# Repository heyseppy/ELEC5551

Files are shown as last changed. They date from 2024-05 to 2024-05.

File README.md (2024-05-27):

<p align="center">
  Satellite Image
  <h1>ELEC5551 Electrical Design Project</h1>
  <p1>27/05/2024</p1>
</p>

## Overview
This repository houses all components of the ELEC5551 Electrical Design project conducted at University of Western Australia. The project includes comprehensive designs and software implementations for a sophisticated electrical system, focusing on both onboard and base station functionalities.

## Repository Overview

### Onboard Hardware
| File Path | Description |
|---|---|
| `Cubesat_PCB/PCB_Project/Project Outputs for Telemetery System ` | Gerber files containing whole project |
| `Cubesat_PCB/PCB_Project/Components` | Team 01's custom footprints.|
| `Cubesat_PCB/PCB_Project/History` | Altium version history cache. |

### Base Station Software
| File Path | Description |
|---|---|
| `Base Station Software/CSV/CSVAppend.py` | Logs GPS data into a CSV, ensuring all entries are unique. |
| `Base Station Software/CSV/NewFlight_csv.py` | Prepares for new data collection by replacing the old CSV with a new template, storing past files.|
| `Base Station Software/GPS_Map/GPSPlot.py` | Plots GPS coordinates on a map and visualizes flight paths with altitude indicated by color. |
| `Base Station Software/GPS_Map/Map_Refresh.py` | Prepares for new GPS plot image, provides template PNG of the map and stores old map. |
| `Base Station Software/MainDataProcessing.py` | Processes data received via serial interface to prepare for display and logging for UI. |
| `Base Station Software/ReadDataFromSerialPort.py` | Initiates data reception from the serial interface. |
| `Base Station Software/Start.py` | Initiates CSV appending process for data logging and process for GPS plotting. |
| `Base Station Software/Stop.py` | Terminates data logging and GPS plotting processes; starts scripts for new templates. |
| `Base Station Software/UI/index.html` | HTML file that structures the user interface layout. |
| `Base Station Software/UI/script.js` | JavaScript file that adds interactivity to the user interface. |
| `Base Station Software/UI/styles.css` | CSS file that styles the user interface elements. |

### Base Station Hardware
| File Path | Description |
|---|---|
| `Base Station Hardware / Base_Station_Combined v34` | Contains entire Autodesk Fusion 360 workspace, including simulation models used for thermal and load analysis. 

### Onboard Software
| File Path | Description |
|---|---|
| `Onboard Software / launch / cubesat_program.py ` | All embedded systems code in micropython for running the project. 
| `Onboard Software / launch / cubesat_launch.py ` | A sample launch file for running all the scripts. 
| `Onboard Software / output / output.json ` | Empty file provided for the output to be generated in. 

### FSM Generator
| File Path | Description |
|---|---|
| `FSM Generator / fsm_generator.html ` | Generates the finite state machine for operation of the on-board telemetry system. 
| `FSM Generator / visualiser.html ` | Constructs a visualiser for the functioning finite state machine. 

## PCB Design
The `PCB` directory contains all necessary files for the Printed Circuit Board (PCB) design. Schematic files, Gerber files, and comprehensive documentation about layout and components are designed using Altium. This design ensures efficiency and reliability, maintaining stable performance under diverse operational conditions.

## Onboard Software
The `OnboardSoftware` folder includes all source code for the microcontrollers on the PCB, written in MicroPython. This software manages sensor inputs, communication protocols, and ensures real-time data processing and decision-making, crucial for the system's autonomous functions.

## Base Station Software
In the `BaseStationSoftware` directory, you'll find the software required to interface with the project's base station. This software is crafted using HTML, CSS, and JavaScript, focusing on data acquisition, user interface, and system monitoring. This stack ensures a robust, user-friendly interface for real-time monitoring and control.

## Base Station Hardware
The `BaseStationHardware` folder encompasses detailed designs and specifications for the hardware setup at the base station, crafted in Autodesk Fusion360. This section provides detailed schematics, a list of components, and assembly instructions, facilitating the building and maintenance of the hardware that supports communication with the onboard systems.

## License
The CERN Open Hardware Licence Version 2 - Permissive (CERN-OHL-P) was chosen for its commitment to transparency and collaboration, allowing unrestricted use, modification, and distribution of the hardware designs and documentation. This license facilitates innovation and sharing within the community, ensuring that all adaptations and improvements remain openly accessible under the same terms.

## Acknowledgements
- Special thanks to the ELEC5551 course staff and fellow students for their invaluable feedback and support.

## Contributors
- Jonathon Sader
- William Hor
- Sep Kimiaei
- Carl Alvares
- Liam Kubach
- Aidan Crummey

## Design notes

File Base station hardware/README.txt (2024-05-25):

.f3z document requires Autodesk fusion 360 to open and view the base station CAD project.

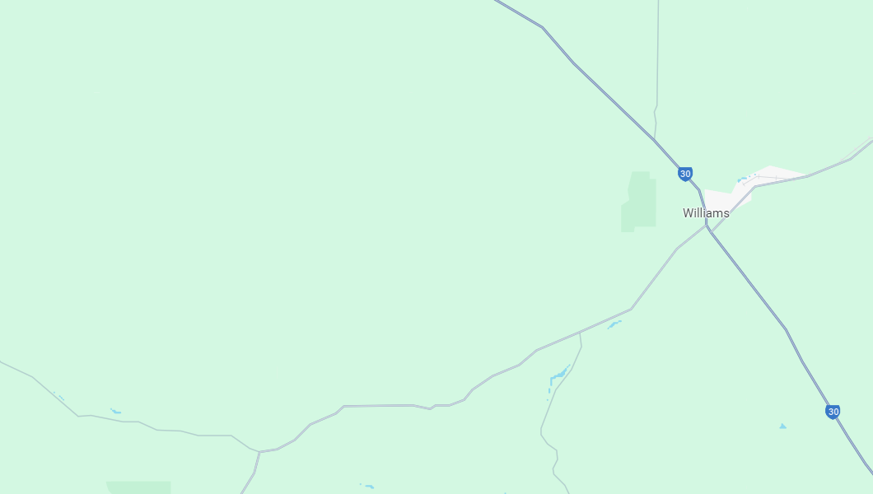
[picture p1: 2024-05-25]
Base station software/GPS_Map/Map Template/template_map.png

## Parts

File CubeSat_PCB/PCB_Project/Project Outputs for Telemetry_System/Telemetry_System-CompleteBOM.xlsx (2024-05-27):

Line # | Name | Description | Designator | Revision ID | Revision State | Revision Status | Quantity | Manufacturer 1 | Manufacturer Part Number 1 | Manufacturer Lifecycle 1 | Supplier 1 | Supplier Part Number 1 | Supplier Unit Price 1 | Supplier Subtotal 1
 | 1 µF | CAP CER 1UF 4V X5R 0402 | C6, C9, C12, C24, C30 |  | Not managed |  | 5 | KYOCERA AVX | 04024D105KAT2A |  | DigiKey | 478-KGM05AR50G105KHCT-ND | 0.02963 | 0.14815
 | 0.1 µF | CAP CER 100NF 10V X7R 0402 | C5, C7, C10, C11, C14, C22, C25, C26, C27, C28 |  | Not managed |  | 12 | Samsung | CL05B104KP5VPNC | Volume Production | Digikey | 1276-CL05B104KP5VPNCCT-ND | 0.0664 | 0.66395
 | 91 kOhms | RES SMD 91K OHM 5% 1/16W 0402 | R10 |  | Not managed |  | 1 | Vishay Dale | CRCW040291K0JNED | Volume Production | Digikey | 541-91KJCT-ND | 0.1509 | 0.1509
 | 511 kOhms | RES SMD 511K OHM 1% 1/16W 0402 | R9 |  | Not managed |  | 1 |  | CRCW0402511KFKED |  | DigiKey | 541-511KLCT-ND | 0.16 | 0.16
 | 10 µF | CAP CER 10UF 4V X5R 0402 | C16, C32, C33 |  | Not managed |  | 4 | Murata | GRM155R60G106ME01D | Volume Production | Digikey | 490-GRM155R60G106ME01DCT-ND | 0.16599 | 0.49796
 | 10000 pF | CAP CER 0402 10NF 16V X7R 10% | C15 |  | Not managed |  | 1 | KEMET | C0402C103K4REC7867 | Volume Production | Digikey | 399-C0402C103K4REC7867CT-ND | 0.16599 | 0.16599
 | 2.2 µF | CAP CER 2.2UF 35V X5R 0402 | C23 |  | Not managed |  | 1 | Murata | GRM155R6YA225KE11D | Volume Production | Digikey | 490-18212-1-ND | 0.24144 | 0.24144
 | 4.7 µF | CAP CER 4.7UF 6.3V X6S 0603 | C4, C20 |  | Not managed |  | 2 | Murata | GRM185C80J475ME11D | Volume Production | Digikey | 490-18660-1-ND | 0.24144 | 0.48287
 | 16 pF | CAP CER 16PF 25V C0G/NP0 0603 | C3, C8 |  | Not managed |  | 2 | KEMET | C0603C160K3GAC7867 | Volume Production | Digikey | 399-C0603C160K3GAC7867CT-ND | 0.28671 | 0.57341
 | 5 pF | CAP CER 5PF 50V 0603 EPOXY | C1, C2 |  | Not managed |  | 2 | TDK | CGA3E2C0G1H050C080AD | Volume Production | Digikey | 445-9797-1-ND | 0.3018 | 0.60359
 | 1 µH | FIXED IND 1UH 1.4A 107 MOHM SMD | L1 |  | Not managed |  | 1 | Murata | LQM2MPN1R0NG0L | Volume Production | Digikey | 490-7784-1-ND | 0.31689 | 0.31689
 | 30 Ohms @ 100 MHz | FERRITE BEAD 30 OHM 0402 1LN | FB1 |  | Not managed |  | 1 | Murata | BLM15PE300SH1D | Volume Production | Digikey | 490-BLM15PE300SH1DCT-ND | 0.31689 | 0.31689
 | 10k | RES 10K OHM 0.1% 1/10W 0402 | R1, R2, R3, R4, R5, R6, R7, R11, R12 |  | Not managed |  | 9 | TE Connectivity | RP73PF1E10KBTD | Volume Production | Digikey | A127415CT-ND | 0.34857 | 3.49
 | 4.7k | RES SMD 4.7K OHM 1% 1/20W 0201 | R13, R14 |  | Not managed |  | 2 | Vishay Dale | CRCW02014K70FKED |  | DigiKey | 541-4.70KAABCT-ND | 0.35 | 0.7
 | 1909763-1 | CONN UMCC JACK STR 50OHM SMD | J1 |  | Not managed |  | 1 | TE Connectivity AMP Connectors | 1909763-1 |  | DigiKey | A118077CT-ND | 0.39526 | 0.39526
 | 47 pF | CAP CER 47PF 16V NP0 0402 | C17, C29 |  | Not managed |  | 2 | KEMET | C0402C470J4GAC7867 | Volume Production | Digikey | 399-14453-1-ND | 0.48287 | 0.96575
 | 47 µF | CAP CER 47UF 4V X5R 0805 | C21 |  | Not managed |  | 1 | Taiyo Yuden | AMK212BBJ476MD-T | Not Recommended for New Design | Digikey | 587-5399-1-ND | 0.55832 | 0.55832
 | 4.7µH | FIXED IND 4.7UH 160MA 2.7 OHM | L2 |  | Not managed |  | 1 | Abracon LLC | AISC-0603F-4R7J-T |  | DigiKey | 535-12533-1-ND | 0.66 | 0.66
 | 22 µF | CAP CER 22UF 10V X5R 0402 | C19 |  | Not managed |  | 1 | Murata | GRM158R61A226ME15D | Volume Production | Digikey | 490-GRM158R61A226ME15DCT-ND | 0.67904 | 0.67904
 | 32.768 kHz | CRYSTAL 32.7680KHZ 12.5PF SMD | Y1 |  | Not managed |  | 1 | Micro Crystal | 201701-MC01 | Unknown | Digikey | 2195-CM8V-T1A-32.768KHZ-12.5PF-20PPM-TB-QACT-ND | 0.7394 | 0.7394
 | 25 MHz | CRYSTAL 25.0000MHZ 18PF SMD | Y2 |  | Not managed |  | 1 | Abracon | ABLS-25.000MHZ-K4F-T | Unknown | Digikey | 535-9956-1-ND | 0.81485 | 0.81485
 | B520C-13-F | DIODE SCHOTTKY 20V 5A SMC | D1 |  | Not managed |  | 1 | Diodes | B520C-13-F | Volume Production | Digikey | B520C-FDICT-ND | 0.84503 | 0.84503
 | S2B-PH-SM4-TB(LF)(SN) | CONN HEADER SMD R/A 2POS 2MM | J6 |  | Not managed |  | 1 |  | S2B-PH-SM4-TB |  | DigiKey | 455-1749-1-ND | 0.93 | 0.93
 | 10 Ohms | TOTAL LEAD-FREE CHIP RESISTOR SU | R8 |  | Not managed |  | 1 | Yageo | SR0402JR-7W10RP | Unknown | Digikey | 13-SR0402JR-7W10RPCT-ND | 0.96575 | 0.96575
 | NPPN061BFLD-RC | CONN HDR 6POS 0.079 GOLD SMD | J8 |  | Not managed |  | 1 | Sullins | NPPN061BFLD-RC | Volume Production | Digikey | S5902-06-ND | 1.09 | 1.09
 | NPPN101BFCN-RC | CONN HDR 10POS 0.079 GOLD PCB | J9, J10 |  | Not managed |  | 2 | Sullins | NPPN101BFCN-RC | Volume Production | Digikey | S5751-10-ND | 1.49 | 2.99
 | J_581-M09-213L462 | 9P D-Sub Panel Mounting 2 Gold - D-Sub / VGA connector ROHS | J7 |  | Not managed |  | 1 | NorComp | 581-M09-213L462 | Volume Production | LCSC | C17556964 | 50.8857 | 50.8857
 | J_B4B-PH-SM4-TB | 1x4P 4P PH Tin 4 -25â„ƒ~+85â„ƒ 2A 1 2mm Copper Alloy Brick nogging SMD,P=2mm Wire To Board Connector ROHS | J2, J3, J5 |  | Not managed |  | 3 | JST | B4B-PH-SM4-TB | Volume Production | LCSC | C160354 | 0.1921 | 0.5763
 | J_DM3CS-SF | 1.83mm Gold Deck MicroSD card (TF card) Pluggable SMD SD Card / Memory Card Connector ROHS | J4 |  | Not managed |  | 1 | HRS(Hirose) | DM3CS-SF | Volume Production | LCSC | C202111 | 1.377 | 1.377
 | NEO-M9N-00B | SMD-24P Satellite Positioning Modules ROHS | U4 |  | Not managed |  | 1 | U-BLOX | NEO-M9N-00B | Volume Production | LCSC | C5119087 | 41.1692 | 41.1692
 | TPS631000DRLR | 2A 1.2V~5.3V 1.6V~5.5V SOT-583 DC-DC Converters ROHS | U5 |  | Not managed |  | 1 | Texas Instruments | TPS631000DRLR | Volume Production | LCSC | C5219190 | 1.6408 | 1.6408
 | U_430182043816 | Round Button 50mA Brick nogging SPST - NO 160gf 12V SMD Tactile Switches ROHS | U2 |  | Not managed |  | 1 | Wurth Elektronik | 430182043816 | Volume Production | LCSC | C5311656 | 0.6183 | 0.6183
 | U_BME280 | LGA-8(2.5x2.5) Temperature and Humidity Sensor ROHS | U9 |  | Not managed |  | 1 | Bosch Sensortec | BME280 | Volume Production | LCSC | C92489 | 3.4287 | 3.4287
 | U_BQ27427YZFR | Polymer 1 DSBGA-9 Battery Management ICs ROHS | U6 |  | Not managed |  | 1 | Texas Instruments | BQ27427YZFR | Volume Production | LCSC | C6075475 | 1.2015 | 1.2015
 | U_LSM9DS1TR | LGA-24(3x3.5) Attitude Sensor/Gyroscope ROHS | U3 |  | Not managed |  | 1 | STMicroelectronics | LSM9DS1TR | Volume Production | LCSC | C2655096 | 7.2046 | 7.2046
 | U_STM32F411CEU6 | 512KB 1.7V~3.6V ARM-M4 128KB 100MHz FLASH 36 UFQFPN-48(7x7) Microcontroller Units (MCUs/MPUs/SOCs) ROHS | U1 |  | Not managed |  | 1 | STMicroelectronics | STM32F411CEU6 | Volume Production | LCSC | C60420 | 2.369 | 2.369
 | U_TCA9406DCUR | 2.3V~5.5V 1 2 1.65V~3.6V 24Mbps VSSOP-8-0.5mm Translators / Level Shifters ROHS | U8 |  | Not managed |  | 1 | Texas Instruments | TCA9406DCUR | Volume Production | LCSC | C840107 | 0.4531 | 0.4531
 | U_TPS62745DSSR | Step-down type WSON-12-EP(2x3) DC-DC Converters ROHS | U7 |  | Not managed |  | 1 | Texas Instruments | TPS62745DSSR | Volume Production | LCSC | C91940 | 0.686 | 0.686
 |  |  |  |  |  |  |  |  |  |  |  |  | Total | 131.75564

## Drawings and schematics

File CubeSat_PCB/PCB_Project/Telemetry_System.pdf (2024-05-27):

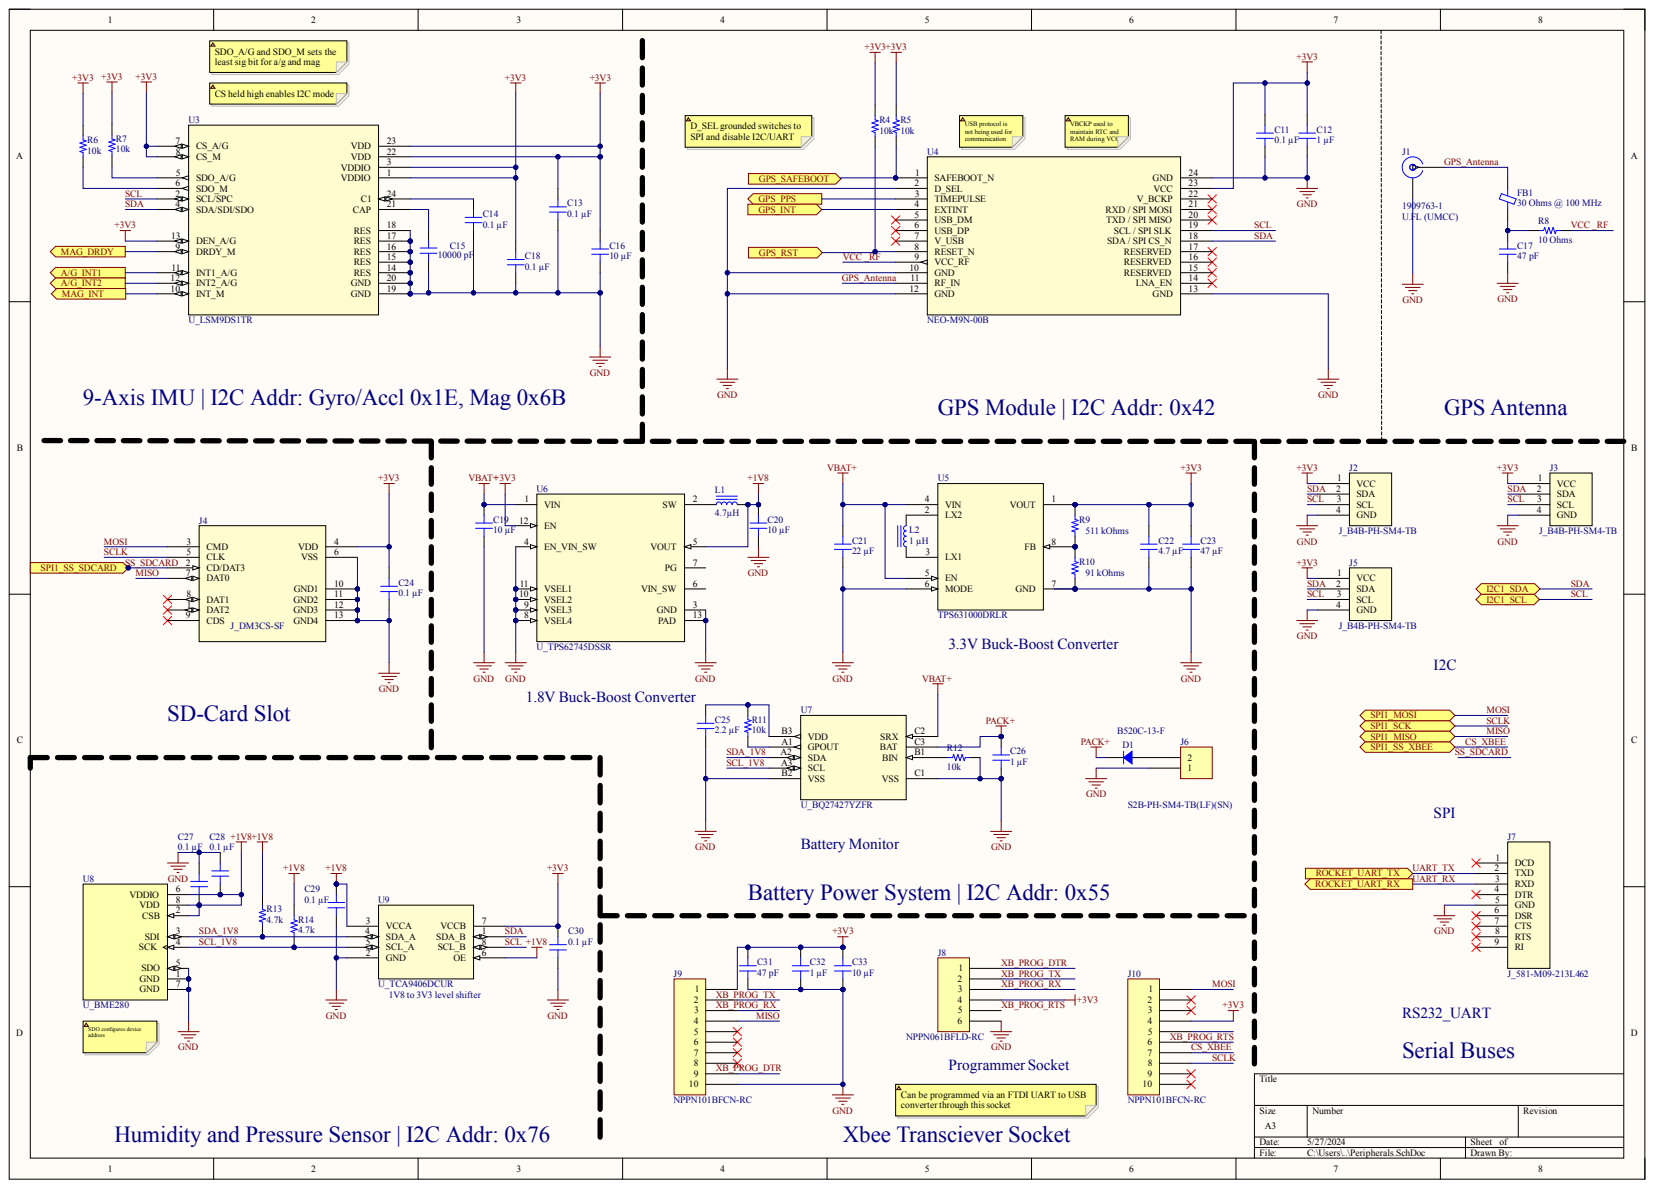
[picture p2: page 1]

SDO_A/G and SDO_M sets the
least sig bit for a/g and mag

CS held high enables I2C mode

D_SELgrounded switches to
SPI and disable I2C/UART

USB protocol is
not being used for
communication

9-Axis IMU | I2C Addr: Gyro/Accl 0x1E, Mag 0x6B

Battery Monitor
Battery Power System | I2C Addr: 0x55

Can be programmed via an FTDI UART to USB
converterthrough thissocket
Xbee Transciever Socket

Humidity and Pressure Sensor | I2C Addr: 0x76

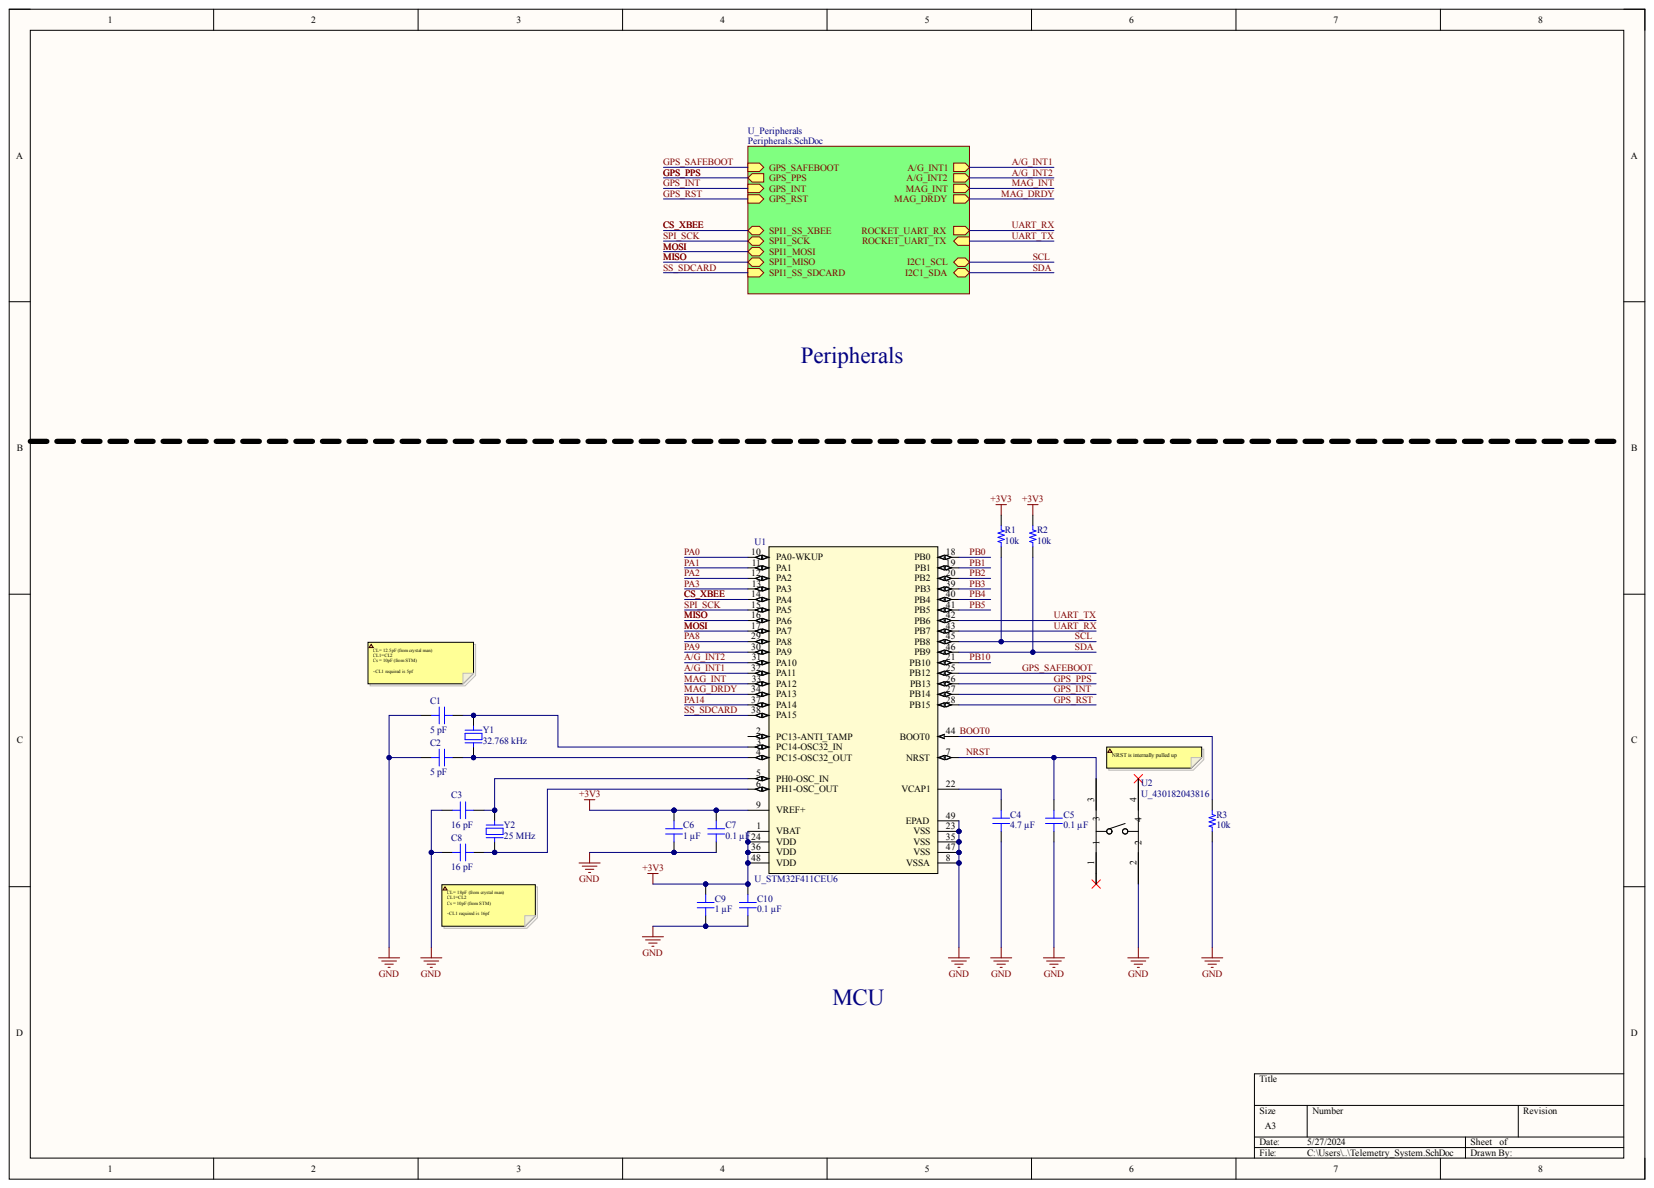
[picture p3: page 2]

CL= 12.5pF (from crystal man)
Cs = 10pF (from STM)

NRST is internally pulled up

CL= 18pF (from crystal man)

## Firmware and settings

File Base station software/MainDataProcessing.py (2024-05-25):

import serial
import hashlib
from cryptography.fernet import Fernet
import json
import os
from PIL import Image
import io

# Define required paths
jsonFilePath = "Main/sensors.json"
current_data_file = "Main/CSV/data_csv.csv"
imageFilePath = "Main/Images/sensor_image.png"

def read_data_from_serial_port():
    with serial.Serial('/dev/ttyUSB0', 9600, timeout=1) as ser:
        return ser.read()

def split_data(packet):
    identifier = packet[0:3]
    encrypted_payload = packet[3:240]
    checksum = packet[240:256]
    return identifier, encrypted_payload, checksum

def verify_checksum(encrypted_payload, checksum):
    calculated_checksum = hashlib.md5(encrypted_payload).hexdigest()
    return calculated_checksum == checksum

def decrypt_payload(encrypted_payload):
    with open("fernet_key_path", "rb") as key_file:
        fernet_key = key_file.read()
    fernet = Fernet(fernet_key)
    decrypted_payload = fernet.decrypt(encrypted_payload)
    return decrypted_payload

def decode_payload_to_json_and_image(decrypted_payload):
    # Assuming payload contains JSON data followed by binary image data
    separator_index = decrypted_payload.find(b'\\end')  # Custom separator between JSON and image data
    json_data = json.loads(decrypted_payload[:separator_index])
    image_data = decrypted_payload[separator_index + 4:]  # Skip the separator
    return json_data, image_data

def save_json_to_file(filename, json_data):
    with open(filename, 'w') as file:
        json.dump(json_data, file)


def save_image_to_file(image_data):
    existing_image_path = "Main/Onboard Pictures/OnBoardPicture_Latest.png"
    past_pictures_folder = "Main/Onboard Pictures/Past Pictures"

    # Timestamp to rename old image
    timestamp = datetime.now().strftime("%Y%m%d_%H%M%S")
    new_image_name = f"OnBoardPicture_{timestamp}.png"
    new_image_path = os.path.join(past_pictures_folder, new_image_name)
    
    # Move old image to Past Pictures Folder
    if os.path.exists(existing_image_path):
        shutil.move(existing_image_path, new_image_path)
    
    # Save new image to existing image path
    image = Image.open(io.BytesIO(image_data))
    image.save(existing_image_path)

def confirm_identifier(identifier):
    return identifier == b'ELEC'

# Main process
while True:
    packet = read_data_from_serial_port()
    if len(packet) == 256:
        identifier, encrypted_payload, checksum = split_data(packet)
        
        if verify_checksum(encrypted_payload, checksum) and confirm_identifier(identifier):
            decrypted_payload = decrypt_payload(encrypted_payload)
            json_data, image_data = decode_payload_to_json_and_image(decrypted_payload)
            save_json_to_file(jsonFilePath, json_data)
            save_image_to_file(imageFilePath, image_data)

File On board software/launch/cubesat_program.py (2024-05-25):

# cubeSat on-board software system
# @ sep kimiaei 2024
from cryptography.fernet import Fernet
# from machine import Pin, ADC
import datetime
import json
import hashlib
import time
from art import *
from sys import getsizeof

# from machine import I2C, Pin, serial

'''
    @author Sep Kimiaei 2024 - ELEC5551 cubeSat design.

    - object orientated approach to develop a cubeSat class with the following functions
    - initiliasation: sets the log file output, transmission frequency and encryption key
    - read_input: 
        @sensor_type:
            "weather" (5 temperature sensors, 1 humidity sensor)
            "imu" (altitude, speed, yaw, bearing)
            "gps" (gps_lat, gps_long, gps_time)
            "diagnostics" (battery)
    - store_data():
        save temporary data array to disk (depending on what file path was given)
    - scale_inputs
        scale all inputs as per their relevant scaling factor.
    - capture_img
        capture frame and store image blob/buffer to temporary data.
    - perform_parity_check
        perform checksum
    - encrypt_data
        use symmetric encryption to store to the image.
    - poll_gps
        store gps_lat, long and time to temporary data.
    - transmit_location
        send location beacon message.
    - transmit_data
        send all encrypted data.

'''

simulation = True

# version 1.0.1
class cubeSat():

    def __init__(self, log_file, transmission_freq, public_key):
        
        # load configuration file for the cubesat
        sensor_file = open('../sensors/sensors.json')
        self.temporary_data = json.load(sensor_file)

        # set output disk file for cubesat onboard memory
        self.log_file = open(log_file, "a")
        self.log_errors = {}

        # set cubesat energisation time (time of flight)
        self.start_time = time.time()

        # configure encryption protocol (Fernet symmetric key)
        self.f = Fernet(str.encode(str(public_key)))
        self.encrypted_data = b''
        
        # set up transmission frequency ticks
        self.transmission_freq = None

        # set up i2c bus. serial lines will be configured as each sensor is called.
        if not simulation:
            self.cubesat_i2c = I2C(0, sda = sda, scl = scl, freq = 4000000)
        else:
            self.cubesat_i2c = None

        self.print_debug()


    def error_management_system(self, error):
        # append error to cubesat's error log
        # use timestamp to mark the key
        time_stamp = time.time()
        self.log_errors[( time_stamp - self.start_time)] = error
        
        print()
        print("!!!!")
        print("Error Occurred at: ")
        print("time-after-launch:", time_stamp)
        print("Details:" , error)
        print()

    def print_debug(self):
        # print debug to help visualise operation
        print()
        loading_screen =text2art("cubeSat  mcu") # return art as str in normal mode
        print(loading_screen)
        print("*"*130)

        print("[-] monitoring: enabled")
        print("[-] transmitting once every:", self.transmission_freq, "seconds")
        print("[-] logging data to:", self.log_file)
        print("[-] loaded in", len(self.temporary_data), "sensor inputs")
        print("[-] current memory usage:", getsizeof(self.temporary_data))
        print("\nconnections: ")
        print("temp1,temp2,temp3,temp4,temp5,speed,altitude,yaw,bearing,humidity,acceleration")
        print("gps_lat,gps_long,gps_time,battery,pressure_1,pressure_2")
        print("camera, xbee")
        print("*"*130)
        print()


    def read_input_sensor(self, data_key):
        '''
            returns the value at the stored address after addressing whether or not it is serial 
            or i2c.
        '''
        if not simulation:
            if self.temporary_data[data_key]["type"] == "i2c":
                _out = self.cubesat_i2c.readfrom(self.temporary_data[data_key]["address"], 1)
            elif self.temporary_data[data_key]["type"] == "serial":
                self.cubesat_serial = Serial(self.temporary_data["address"])
                _out = self.cubesat_serial_port.read(self.temporary_data[data_key]["address"])
        else:
            _out = -1
        # return the output data (analog)
        return _out
    

    def read_inputs(self,sensor_type):

        print("reading sensor:", sensor_type)
        print()
        
        if not simulation:
            if (sensor_type == "weather"):
                
                
                self.temporary_data["temp1"]          = self.read_input_sensor("temp1")
                self.temporary_data["temp2"]          = self.read_input_sensor("temp2")
                self.temporary_data["temp3"]          = self.read_input_sensor("temp3")
                self.temporary_data["temp4"]          = self.read_input_sensor("temp4")
                self.temporary_data["temp5"]          = self.read_input_sensor("temp5")

                # humidity
                self.temporary_data["humidity"]       = self.read_input_sensor("humidity")

                # pressure
                self.temporary_data["pressure_1"]     = self.read_input_sensor("pressure_1")
                self.temporary_data["pressure_2"]     = self.read_input_sensor("pressure_2")

            elif (sensor_type == "imu"):
                self.temporary_data["speed"]          = self.read_input_sensor("speed")
                self.temporary_data["acceleration"]   = self.read_input_sensor("acceleration")
                self.temporary_data["altitude"]       = self.read_input_sensor("altitude")
                self.temporary_data["bearing"]        = self.read_input_sensor("bearing")

            elif (sensor_type == "gps"):
                self.temporary_data["gps_lat"]        = self.read_input_sensor("gps_lat")
                self.temporary_data["gps_long"]       = self.read_input_sensor("gps_long")
                self.temporary_data["gps_time"]       = self.read_input_sensor("gps_time")

            elif (sensor_type == "diagnostics"):
                self.temporary_data["battery"]        = self.read_input_sensor("battery")

            # otherwise return None
            else:
                print("no sensor was selected")
                return

    def wait(self, period):
        time.sleep(period)
    
    def store_data(self):
        '''
            stores data to disk.
            after discussion with client, the on-metal data will not need to be encrypted.
        '''
        print("stored to file:", self.log_file)
        temporary_log_file_str = json.dumps(self.temporary_data, sort_keys=True)

        # format would be string iso time + dictionary array
        self.log_file.write(f"{str(datetime.datetime.now())} - {temporary_log_file_str}")
        print("[-] current memory usage:", getsizeof(self.temporary_data))
        print()
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

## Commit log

2024-04-08 created altium project
    [Telemetry_System.PrjPcb, Telemetry_System.SchDoc]
2024-04-14 added sensors
2024-04-23 created schematic files for each component
    [BMC.SchDoc, GPS.SchDoc, IMU.SchDoc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]
2024-04-23 added stm32 mcu to mcu schematic
    [MCU.SchDoc, Telemetry_System.PrjPcb, Telemetry_System.SchDoc]
2024-05-04 added components
    [BMC.SchDoc, CSTCE8M00G15L99-R0.PcbLib, CSTCE8M00G15L99-R0.SchLib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]
2024-05-06 Added clocks and most components
    [MCU.SchDoc]
2024-05-06 moved MCu schematics to new page to set default grid
    [MCU.SchDoc]
2024-05-06 sheets moved around
    [TPS82698SIPR.SchLib, Telemetry_System.PrjPcb, Telemetry_System.SchDoc]
2024-05-11 added gps module
    [NEO-M9N-00B.PcbLib, NEO-M9N-00B.SchLib]
2024-05-11 updated names with identifiers
    [CSTCE8M00G15L99-R0.SchLib, GPS.SchDoc, NEO-M9N-00B.SchLib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]
2024-05-11 intermediate backup (added resistors and antenna)
    [CSTCE8M00G15L99-R0.PcbLib, U_CSTCE8M00G15L99-R0.SchLib]
2024-05-11 changed comments to include name of chip
    [U_NEO-M9N-00B.SchLib, U_TPS82698SIPR.SchLib]
2024-05-11 mostly finished
    [GPS.SchDoc]
2024-05-11 schematic complete. just need to add harnesses and stuff
    [GPS.SchDoc]
2024-05-11 gps done
    [GPS.SchDoc, MCU.SchDoc, Telemetry_System.PrjPcb]
2024-05-11 added humidity sensor component
    [BME280.PcbLib, BME280.SchLib, Telemetry_System.PrjPcb]
2024-05-11 finished gps and pressure sensor
    [GPS.SchDoc, IMU.SchDoc, MCU.SchDoc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]
2024-05-11 renamed BME
    [BME280.PcbLib, BME280.SchLib, U_BME280.SchLib]
2024-05-11 Added level shifter component
    [TCA9406DCUR.PcbLib, U_TCA9406DCUR.SchLib]
2024-05-11 added imu
    [LSM9DS1TR.PcbLib, U_LSM9DS1TR.SchLib]
2024-05-11 Commit before rename
    [GPS.SchDoc, Pressure_and_Humidity.SchDoc]
2024-05-11 rename to peripherals
    [GPS.SchDoc]
2024-05-12 mode sda and scl together
    [U_LSM9DS1TR.SchLib]
2024-05-12 moved sdo to top
    [U_LSM9DS1TR.SchLib]
2024-05-12 finished IMU schematics
    [Peripherals.SchDoc]
2024-05-12 added sd card holder
    [DM3CS-SF.PcbLib, J_DM3CS-SF.SchLib]
2024-05-12 Finished sd card slot
    [Peripherals.SchDoc]
2024-05-12 chagned template schematic
    [BMC.SchDoc, MCU.SchDoc, SD_Card.SchDoc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]
2024-05-12 sd card done
    [Peripherals.SchDoc]
2024-05-12 deleted sd card sheet as not required
    [SD_Card.SchDoc]
2024-05-12 added designators and headings to be expanded on
    [Peripherals.SchDoc, Telemetry_System.PcbDoc, Telemetry_System.PrjPcb]
2024-05-16 Added XBEE module headers
    [MCU.SchDoc, Peripherals.SchDoc, Telemetry_System.PcbDoc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]
2024-05-16 import prefs from poe board
2024-05-17 added 3v3 buck boost
    [TPS631000DRLR.PcbLib, U_TPS631000DRLR.SchLib]
2024-05-17 added buck boost
    [MCU.SchDoc, Peripherals.SchDoc, Telemetry_System.PrjPcb]
2024-05-17 added battery monitor module, DB9, buck converter
    [581-M09-213L462.PcbLib, BQ27427YZFR.PcbLib, J_581-M09-213L462.SchLib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]
2024-05-17 did some stuff
    [Peripherals.SchDoc, Telemetry_System.PrjPcb]
2024-05-18 remove unnecessary pages
    [BMC.SchDoc, Telemetry_System.SchDoc]
2024-05-18 finished peripherals sheet
    [MCU.SchDoc, Peripherals.SchDoc, Telemetry_System.PrjPcb]
2024-05-18 intermediate update
    [U_BQ27427YZFR.SchLib]
2024-05-18 renamed mcu to telemetry
    [MCU.SchDoc, Peripherals.SchDoc, Telemetry_System.SchDoc]
2024-05-18 FINISHED 1st rev
    [Peripherals.SchDoc, Telemetry_System.PrjPcb, Telemetry_System.SchDoc]
2024-05-18 BOM and pdf generated
2024-05-18 final push after schematics done
    [Telemetry_System.PrjPcb, U_430182043816.SchLib]
2024-05-23 layout complete - need to route
    [Peripherals.SchDoc, Telemetry_System.PcbDoc, Telemetry_System.PrjPcb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]
2024-05-23 added 3d bodies
    [430182043816.PcbLib, B4B-PH-SM4-TB.PcbLib, BME280.PcbLib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]
2024-05-23 partial routing complete
    [Peripherals.SchDoc, Telemetry_System.PcbDoc]
2024-05-24 More routing complete
    [Peripherals.SchDoc, Telemetry_System.PrjPcb, Telemetry_System.SchDoc]
2024-05-25 Current fusion revision and README.txt
2024-05-25 ROUTING COMPLETE!!!
    [Peripherals.SchDoc, Telemetry_System.PrjPcb, Telemetry_System.SchDoc]
2024-05-25 attach 3d bodies
    [BAT_LP735977JH.SchLib, BME280.PcbLib, J_DM3CS-SF.SchLib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]
2024-05-25 final commit
    [Telemetry_System.PrjPcb]
2024-05-25 templare for dara csv
    [template_data_csv.xlsx]
2024-05-25 removed I2C protocol buffering
2024-05-26 updated name
    [BT_LP735977JH.SchLib]
2024-05-26 updated annotations
    [Peripherals.SchDoc, Telemetry_System-CompleteBOM.xlsx, Telemetry_System-reqd components.xlsx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]
2024-05-26 renamed folder workspace
    [template_data_csv.xlsx]
2024-05-26 export 3d files and add battery 3d body
    [Telemetry_System.SchDoc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]
2024-05-27 schematic pdf updated
    [Telemetry_System.PrjPcb]
2024-05-27 updated pdf (only schematics)
2024-05-27 gerbers zipped for use with JLC PCB
2024-05-27 fixed net name for xbee
    [Peripherals.SchDoc]
2024-05-27 added customised component footprints
